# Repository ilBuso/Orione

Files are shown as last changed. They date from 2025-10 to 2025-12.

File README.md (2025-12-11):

# Orione

Orione is a custom 60% mechanical keyboard powered by Raspberry Pi Pico.

## Table of Contents

- [About the Project](#about-the-project)
- [Key Features](#key-features)
- [Making It Your Own](#making-it-your-own)
- [What You'll Need](#what-youll-need)
  - [Hardware Components](#hardware-components)
  - [Software Tools](#software-tools)
- [The PCB](#the-pcb)
- [The Chassis](#the-chassis)
- [Project layout](#project-layout)
- [Video and Presentation](#video-and-presentation)
- [The Team](#the-team)

## About the Project

The need for a keyboard with a rotary encoder that could be customized without compromising on functionality sparked the creation of this project. When existing options fell short of meeting these requirements, Orione was born: a custom 60% mechanical keyboard powered by the Raspberry Pi Pico, featuring fully customizable firmware and a dual-layer system that packs maximum functionality into a minimal footprint.

Orione is built around the compact 60% keyboard layout, which strips away the function row and number pad to create a more ergonomic typing experience. At its heart is the Raspberry Pi Pico microcontroller, an affordable and reliable brain that handles everything from key presses to USB communication.

What makes Orione special is its programmable dual-layer system. Through a dedicated function key, you can access an entirely separate layer of key functions, meaning you don't lose any functionality despite the smaller form factor. It's like having two keyboards in one compact package.

## Key Features

The design philosophy behind Orione was simple: create something that feels personal and works exactly the way I want it to. Here's what that translated into:

The **60% layout** keeps everything within easy reach, no more stretching for distant keys or function rows. A **dual-layer system** accessed through a dedicated function key means I haven't sacrificed any functionality for compactness.

The **rotary encoder** handles volume control beautifully, with raise, lower, and mute functionality at your fingertips. There's also a **Caps Lock LED indicator** for quick visual feedback.

For switches are for the most part **Gateron Yellow switches** that provide smooth linear action for most keys, while **Gateron Blue switches** offer tactile feedback on select keys where I wanted that extra confirmation.

Most importantly, the firmware is **fully customizable**. Every key can be remapped, every function can be changed. The Raspberry Pi Pico makes this possible, and the open-source nature of the project means you're never locked into my choices.

## Making It Your Own

One of Orione's defining features is how easily you can make it yours. The firmware is completely open and modifiable. Want to change what a key does? Remap the function layer? It's all possible:

Start by editing the keymap configuration files to match your preferences. Once you're happy with your changes, recompile the firmware and flash it to your Raspberry Pi Pico. That's it, you've got a personalized keyboard that works exactly the way you want it to.

## What You'll Need

### Hardware Components

Building Orione requires a carefully selected set of components. You'll need a **Raspberry Pi Pico** as the microcontroller, it's the brain of the operation. The **rotary encoder** provides that tactile volume control I was after, while a **LED** serves as the Caps Lock indicator.s

For the switches, you'll need **62 mechanical switches** total. You'll also need a matching set of **62 keycaps** and **62 diodes** for the key matrix.

Finally, there's the **custom PCB** that I designed specifically for this project, bringing all these components together in a compact and functional layout.

### Software Tools

The development environment revolves around **VS Code**, which I used for writing and debugging the firmware. For the PCB design, **KiCad** handled both the schematics and the layout. The chassis and 3D components were modeled in **Blender**.

On the firmware side, the project uses the **Raspberry Pi Pico C/C++ SDK**, following the official _Getting Started guide_ will get you set up properly. The **TinyUSB Library** is crucial here, as it enables USB HID communication between the Pico and your computer through the micro USB port, making the keyboard actually function as, well, a keyboard.

## The PCB

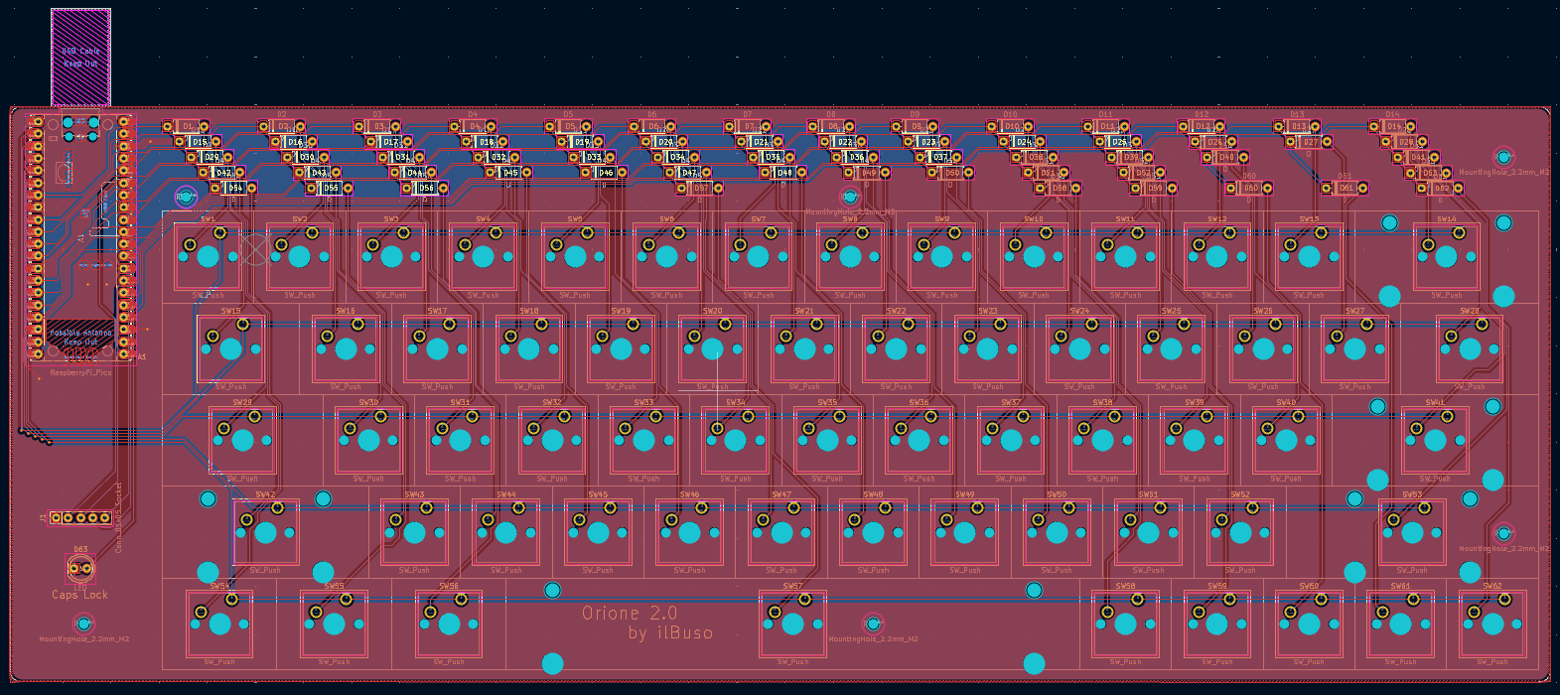
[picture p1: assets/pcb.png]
PCB


## The Chassis

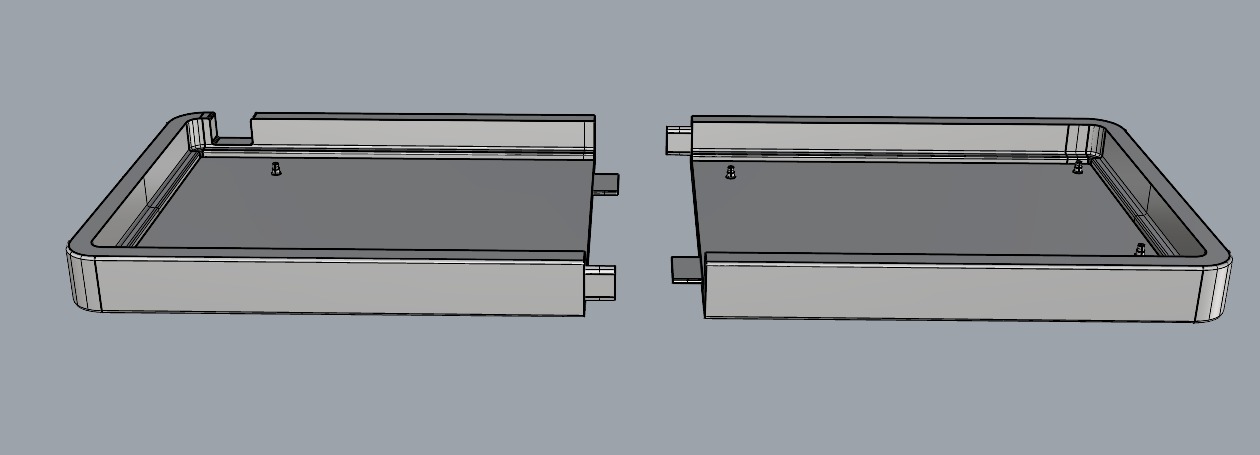
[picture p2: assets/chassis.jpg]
Chassis


## Project layout

```
/
├───datasheets
|   └───...
├───firmware
│   ├───config
│   └───src
│       ├───init
│       │   ├───init.h
│       │   └───init.c
│       ├───interrupts
│       │   ├───interrupts.h
│       │   └───interrupts.c
│       ├───matrix
│       │   ├───keymap
│       │   │   ├───keymap.h
│       │   │   └───keymap.c
│       │   └───scan_rows
│       │       ├───scan_rows.h
│       │       └───scan_rows.c
│       ├───rotary_encoder
│       │   ├───rotary_encoder.h
│       │   └───rotary_encoder.c
│       └───usb
│           ├───usb_callbacks
│           │  ├───usb_callbacks.h
│           │  └───usb_callbacks.c
│           └───usb_descriptors
│              ├───usb_descriptors.h
│              └───usb_descriptors.c
├───pcb
│   └───...
└───chassis
    └───...
```

## Video and Presentation

[Video](https://youtu.be/jeuJEti2THU)

[Presentation](assets/Orione.pdf)

## The Team

In the team we collaborated closely with eachother, both in presence and through Github.

|Name|Github handle|
|---|---|
|Alessandro Busola| [@ilBuso](https://github.com/ilBuso)|
|Giulio Pimenoff Verdolin|[@Giuliopime](https://github.com/Giuliopime)|
|Michele Pezzo|[@MichelePZZ](https://github.com/MichelePZZ)|
|Daniel Biz|[@BizDaniel](https://github.com/BizDaniel)|

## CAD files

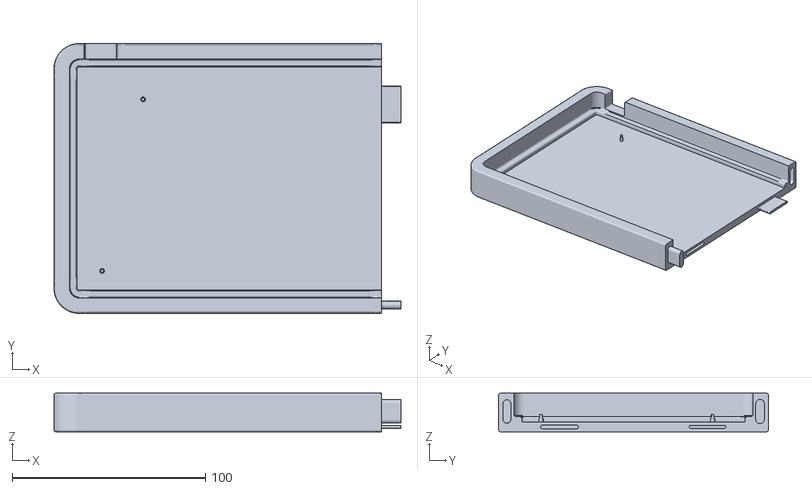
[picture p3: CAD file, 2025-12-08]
chassis/Chasis_Hor_1.stl
179.4 x 139.5 x 20.0

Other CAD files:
chassis/Chasis_Hor_2.stl

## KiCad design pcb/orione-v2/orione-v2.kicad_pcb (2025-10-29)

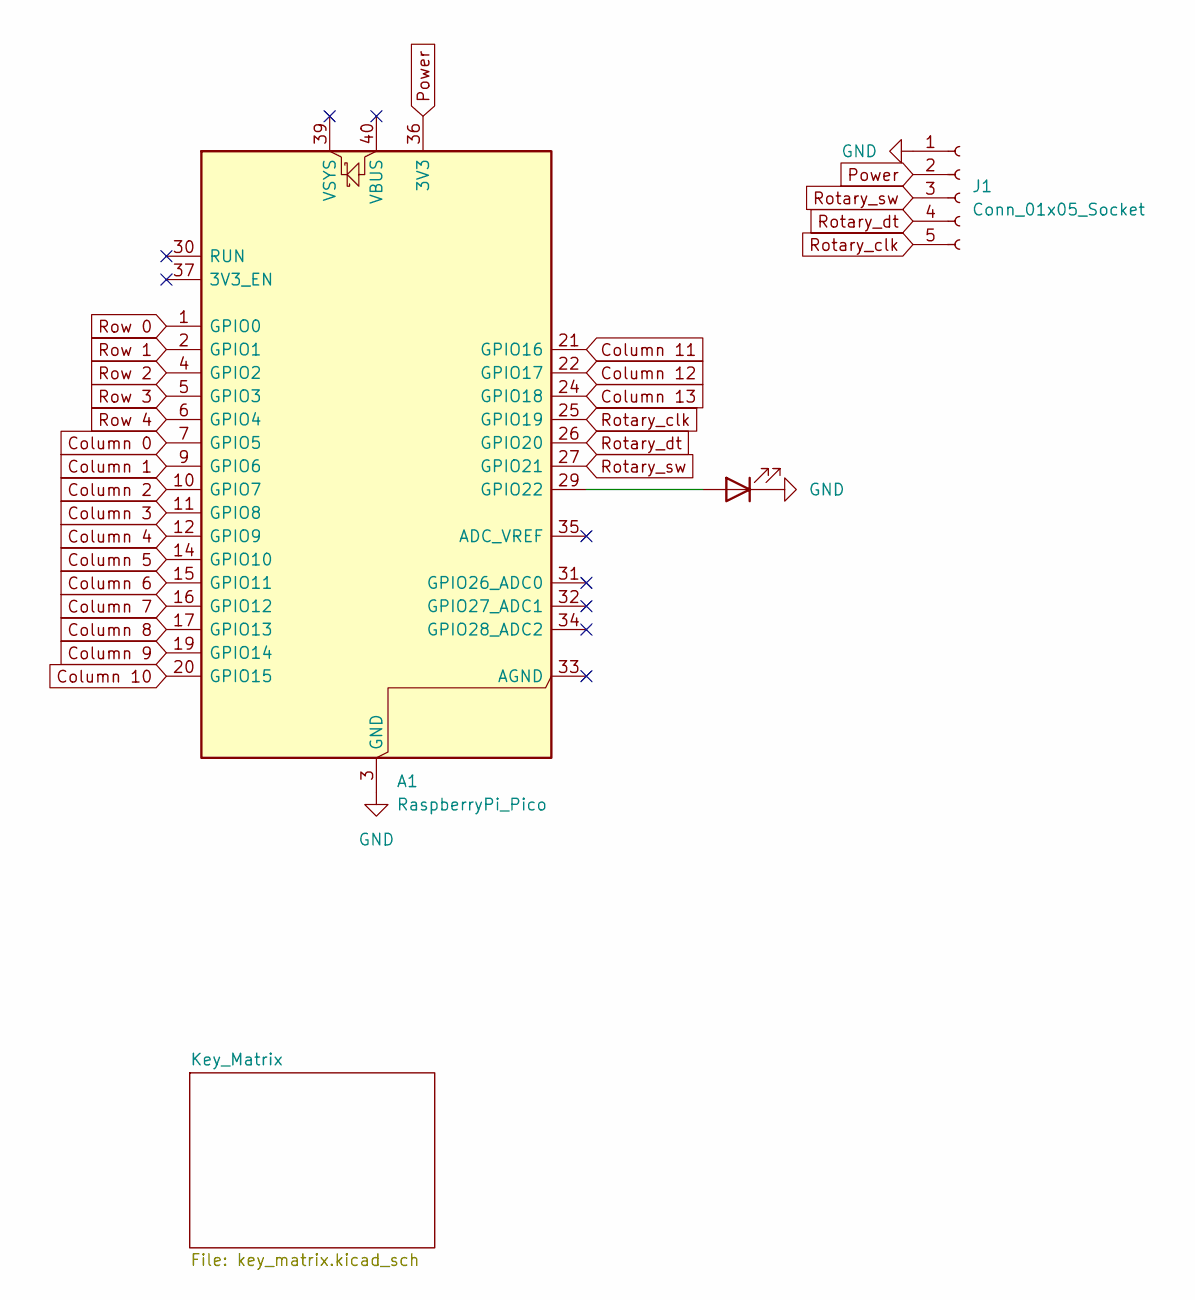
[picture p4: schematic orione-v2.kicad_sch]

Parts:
A1: RaspberryPi_Pico; RaspberryPi_Pico_Common_Unspecified
D63: LED; LED_D5.0mm
J1: Conn_01x05_Socket; PinSocket_1x05_P2.54mm_Vertical

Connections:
Column 0: A1.7 (GPIO5); also elsewhere on the board
Column 1: A1.9 (GPIO6); also elsewhere on the board
Column 2: A1.10 (GPIO7); also elsewhere on the board
Column 3: A1.11 (GPIO8); also elsewhere on the board
Column 4: A1.12 (GPIO9); also elsewhere on the board
Column 5: A1.14 (GPIO10); also elsewhere on the board
Column 6: A1.15 (GPIO11); also elsewhere on the board
Column 7: A1.16 (GPIO12); also elsewhere on the board
Column 8: A1.17 (GPIO13); also elsewhere on the board
Column 9: A1.19 (GPIO14); also elsewhere on the board
Column 10: A1.20 (GPIO15); also elsewhere on the board
Column 11: A1.21 (GPIO16); also elsewhere on the board
Column 12: A1.22 (GPIO17); also elsewhere on the board
Column 13: A1.24 (GPIO18); also elsewhere on the board
GND: A1.3 (GND), A1.8 (GND), A1.13 (GND), A1.18 (GND), A1.23 (GND), A1.28 (GND), A1.38 (GND), D63.1 (K), J1.1
unnamed: A1.29 (GPIO22), D63.2 (A)
Power: A1.36 (3V3), J1.2
Rotary_clk: A1.25 (GPIO19), J1.5
Rotary_dt: A1.26 (GPIO20), J1.4
Rotary_sw: A1.27 (GPIO21), J1.3
Row 0: A1.1 (GPIO0); also elsewhere on the board
Row 1: A1.2 (GPIO1); also elsewhere on the board
Row 2: A1.4 (GPIO2); also elsewhere on the board
Row 3: A1.5 (GPIO3); also elsewhere on the board
Row 4: A1.6 (GPIO4); also elsewhere on the board

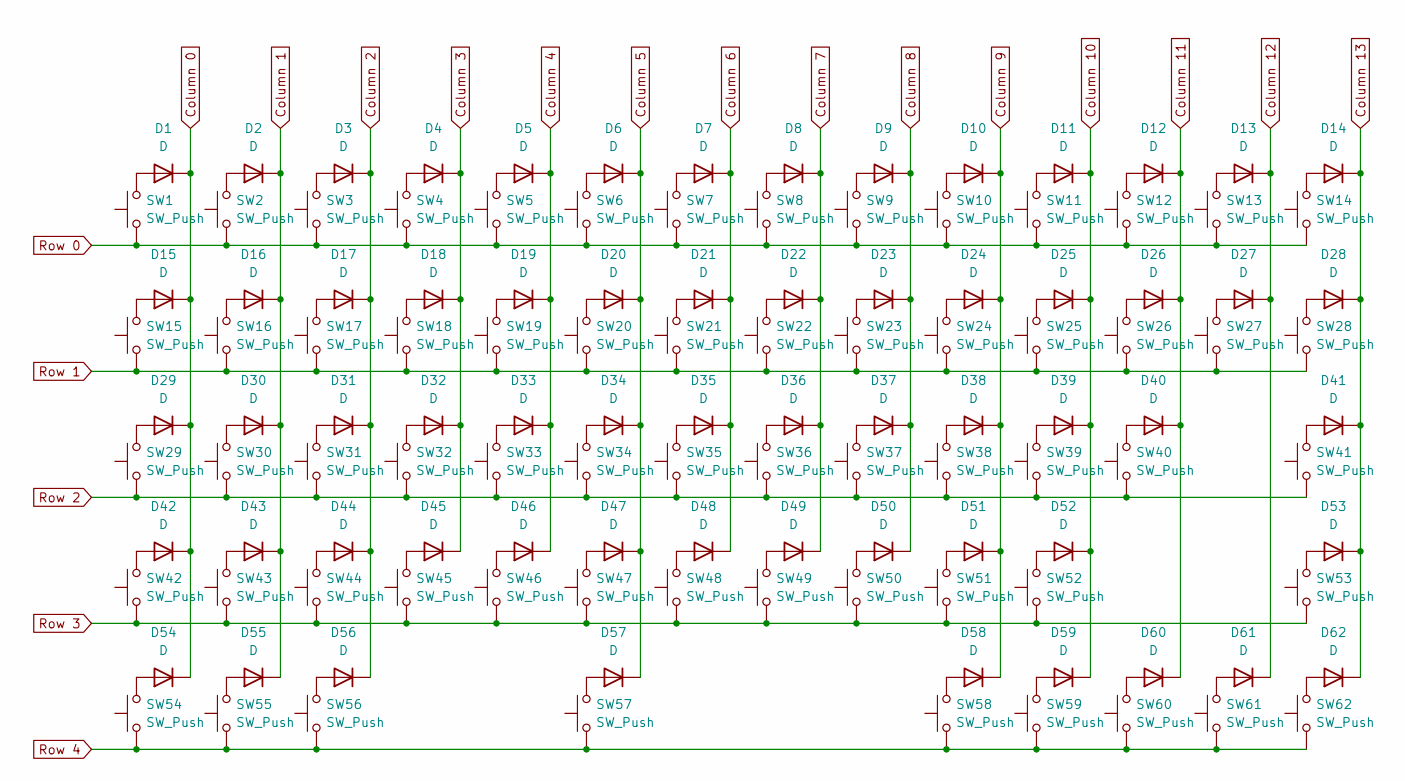
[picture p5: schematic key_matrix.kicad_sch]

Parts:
D1, D2, D3, D4, D5, D6, D7, D8, D9, D10, D11, D12, D13, D14, D15, D16, D17, D18, D19, D20, D21, D22, D23, D24, D25, D26, D27, D28, D29, D30, D31, D32, D33, D34, D35, D36, D37, D38, D39, D40, D41, D42, D43, D44, D45, D46, D47, D48, D49, D50, D51, D52, D53, D54, D55, D56, D57, D58, D59, D60, D61, D62: D; D_A-405_P7.62mm_Horizontal
SW1, SW2, SW3, SW4, SW5, SW6, SW7, SW8, SW9, SW10, SW11, SW12, SW13, SW16, SW17, SW18, SW19, SW20, SW21, SW22, SW23, SW24, SW25, SW26, SW27, SW30, SW31, SW32, SW33, SW34, SW35, SW36, SW37, SW38, SW39, SW40, SW43, SW44, SW45, SW46, SW47, SW48, SW49, SW50, SW51, SW52, SW58, SW59, SW60, SW61, SW62: SW_Push; SW_Cherry_MX_1.00u_PCB
SW14: SW_Push; SW_Cherry_MX_2.00u_PCB
SW15, SW28: SW_Push; SW_Cherry_MX_1.50u_PCB
SW29: SW_Push; SW_Cherry_MX_1.75u_PCB
SW41, SW42: SW_Push; SW_Cherry_MX_2.25u_PCB
SW53: SW_Push; SW_Cherry_MX_2.75u_PCB
SW54, SW55, SW56: SW_Push; SW_Cherry_MX_1.25u_PCB
SW57: SW_Push; SW_Cherry_MX_6.25u_PCB

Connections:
Column 0: D1.1 (K), D15.1 (K), D29.1 (K), D42.1 (K), D54.1 (K); also elsewhere on the board
Column 1: D2.1 (K), D16.1 (K), D30.1 (K), D43.1 (K), D55.1 (K); also elsewhere on the board
Column 2: D3.1 (K), D17.1 (K), D31.1 (K), D44.1 (K), D56.1 (K); also elsewhere on the board
Column 3: D4.1 (K), D18.1 (K), D32.1 (K), D45.1 (K); also elsewhere on the board
Column 4: D5.1 (K), D19.1 (K), D33.1 (K), D46.1 (K); also elsewhere on the board
Column 5: D6.1 (K), D20.1 (K), D34.1 (K), D47.1 (K), D57.1 (K); also elsewhere on the board
Column 6: D7.1 (K), D21.1 (K), D35.1 (K), D48.1 (K); also elsewhere on the board
Column 7: D8.1 (K), D22.1 (K), D36.1 (K), D49.1 (K); also elsewhere on the board
Column 8: D9.1 (K), D23.1 (K), D37.1 (K), D50.1 (K); also elsewhere on the board
Column 9: D10.1 (K), D24.1 (K), D38.1 (K), D51.1 (K), D58.1 (K); also elsewhere on the board
Column 10: D11.1 (K), D25.1 (K), D39.1 (K), D52.1 (K), D59.1 (K); also elsewhere on the board
Column 11: D12.1 (K), D26.1 (K), D40.1 (K), D60.1 (K); also elsewhere on the board
Column 12: D13.1 (K), D27.1 (K), D61.1 (K); also elsewhere on the board
Column 13: D14.1 (K), D28.1 (K), D41.1 (K), D53.1 (K), D62.1 (K); also elsewhere on the board
unnamed: D1.2 (A), SW1.2
unnamed: D2.2 (A), SW2.2
unnamed: D3.2 (A), SW3.2
unnamed: D4.2 (A), SW4.2
unnamed: D5.2 (A), SW5.2
unnamed: D6.2 (A), SW6.2
unnamed: D7.2 (A), SW7.2
unnamed: D8.2 (A), SW8.2
unnamed: D9.2 (A), SW9.2
unnamed: D10.2 (A), SW10.2
unnamed: D11.2 (A), SW11.2
unnamed: D12.2 (A), SW12.2
unnamed: D13.2 (A), SW13.2
unnamed: D14.2 (A), SW14.2
unnamed: D15.2 (A), SW15.2
unnamed: D16.2 (A), SW16.2
unnamed: D17.2 (A), SW17.2
unnamed: D18.2 (A), SW18.2
unnamed: D19.2 (A), SW19.2
unnamed: D20.2 (A), SW20.2
unnamed: D21.2 (A), SW21.2
unnamed: D22.2 (A), SW22.2
unnamed: D23.2 (A), SW23.2
unnamed: D24.2 (A), SW24.2
unnamed: D25.2 (A), SW25.2
unnamed: D26.2 (A), SW26.2
unnamed: D27.2 (A), SW27.2
unnamed: D28.2 (A), SW28.2
unnamed: D29.2 (A), SW29.2
unnamed: D30.2 (A), SW30.2
unnamed: D31.2 (A), SW31.2
unnamed: D32.2 (A), SW32.2
unnamed: D33.2 (A), SW33.2
unnamed: D34.2 (A), SW34.2
unnamed: D35.2 (A), SW35.2
unnamed: D36.2 (A), SW36.2
unnamed: D37.2 (A), SW37.2
unnamed: D38.2 (A), SW38.2
unnamed: D39.2 (A), SW39.2
unnamed: D40.2 (A), SW40.2
unnamed: D41.2 (A), SW41.2
unnamed: D42.2 (A), SW42.2
unnamed: D43.2 (A), SW43.2
unnamed: D44.2 (A), SW44.2
unnamed: D45.2 (A), SW45.2
unnamed: D46.2 (A), SW46.2
unnamed: D47.2 (A), SW47.2
unnamed: D48.2 (A), SW48.2
unnamed: D49.2 (A), SW49.2
unnamed: D50.2 (A), SW50.2
unnamed: D51.2 (A), SW51.2
unnamed: D52.2 (A), SW52.2
unnamed: D53.2 (A), SW53.2
unnamed: D54.2 (A), SW54.2
unnamed: D55.2 (A), SW55.2
unnamed: D56.2 (A), SW56.2
unnamed: D57.2 (A), SW57.2
unnamed: D58.2 (A), SW58.2
unnamed: D59.2 (A), SW59.2
unnamed: D60.2 (A), SW60.2
unnamed: D61.2 (A), SW61.2
unnamed: D62.2 (A), SW62.2
Row 0: SW1.1, SW2.1, SW3.1, SW4.1, SW5.1, SW6.1, SW7.1, SW8.1, SW9.1, SW10.1, SW11.1, SW12.1, SW13.1, SW14.1; also elsewhere on the board
Row 1: SW15.1, SW16.1, SW17.1, SW18.1, SW19.1, SW20.1, SW21.1, SW22.1, SW23.1, SW24.1, SW25.1, SW26.1, SW27.1, SW28.1; also elsewhere on the board
Row 2: SW29.1, SW30.1, SW31.1, SW32.1, SW33.1, SW34.1, SW35.1, SW36.1, SW37.1, SW38.1, SW39.1, SW40.1, SW41.1; also elsewhere on the board
Row 3: SW42.1, SW43.1, SW44.1, SW45.1, SW46.1, SW47.1, SW48.1, SW49.1, SW50.1, SW51.1, SW52.1, SW53.1; also elsewhere on the board
Row 4: SW54.1, SW55.1, SW56.1, SW57.1, SW58.1, SW59.1, SW60.1, SW61.1, SW62.1; also elsewhere on the board

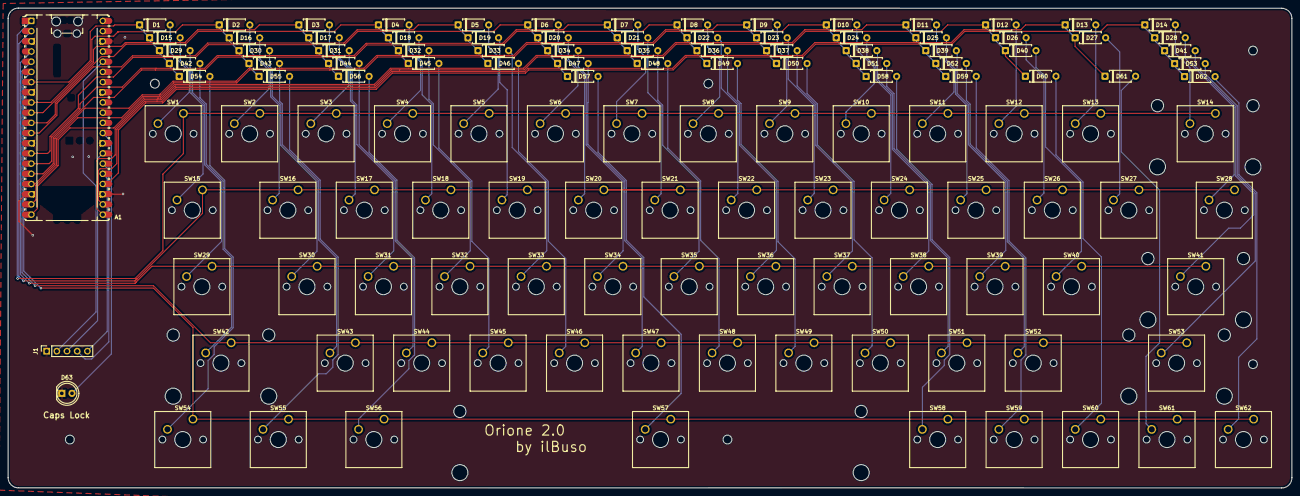
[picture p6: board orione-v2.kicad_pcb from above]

Board: 2 copper layers, 319.9 x 119.6 mm, 127 parts (0 on the bottom side), 87 nets.

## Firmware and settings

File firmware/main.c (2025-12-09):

/**
 * @file main.c
 * @brief Main entry point for Orione keyboard firmware
 * 
 * Handles USB device initialization, main loop execution, LED status blinking,
 * and HID report generation for both keyboard matrix and rotary encoder inputs.
 */

#include <stdlib.h>
#include <stdio.h>
#include <string.h>

#include "pico/stdlib.h"
#include "bsp/board_api.h"
#include "tusb.h"

#include "src/usb/usb_descriptors/usb_descriptors.h"
#include "src/usb/usb_callbacks/usb_callbacks.h"
#include "src/global.h"
#include "src/init/init.h"
#include "src/matrix/scan_rows/scan_rows.h"

//--------------------------------------------------------------------+

uint32_t blink_interval_ms = BLINK_NOT_MOUNTED;

keyboard_state_t kbd_state = {
    .has_new_key = false,
    .pressed_keys_count = 0,
    .current_layer = 0
};

//--------------------------------------------------------------------+

/**
 * @brief Blink onboard LED based on USB connection status
 * 
 * Provides visual feedback of the device state:
 * - Fast blink (250ms): Not mounted/connected
 * - Slow blink (1000ms): Mounted and ready
 * - Very slow blink (2500ms): Suspended
 * - Solid on: Caps Lock active
 * - Off: Blink disabled
 */
void led_blinking_task(void) {
    static uint32_t start_ms = 0;
    static bool led_state = false;

    // blink is disabled
    if (!blink_interval_ms) return;

    // Blink every interval ms
    if (board_millis() - start_ms < blink_interval_ms) return;
    start_ms += blink_interval_ms;

    board_led_write(led_state);
    led_state = 1 - led_state;
}

/**
 * @brief Process and send HID reports for keyboard and rotary encoder
 * 
 * Polls keyboard state and rotary encoder at 10ms intervals (required by TinyUSB).
 * Handles:
 * - Remote wakeup when suspended
 * - Keyboard key press/release reports
 * - Rotary encoder volume control (rotation) and mute (button press)
 */
void hid_task(void) {
    // Poll every 10ms -> required by TinyUSB
    const uint32_t interval_ms = 10;
    static uint32_t start_ms = 0;

    // check interval
    if (board_millis() - start_ms < interval_ms) return;
    start_ms += interval_ms;

    // Remote wakeup if suspended
    if (tud_suspended()) {
        if (kbd_state.has_new_key) {
            tud_remote_wakeup();
            kbd_state.has_new_key = false;
        }
        return;
    } else {
        if (tud_hid_ready()) {
            // Handle keyboard input
            if (kbd_state.has_new_key) {
                // Clear flag
                kbd_state.has_new_key = false;
                // send report
                send_hid_report(REPORT_ID_KEYBOARD, 0);
            }

            // Handle rotary encoder input
            int8_t direction;
            bool button_pressed;
            
            rotary_encoder_get_state(&direction, &button_pressed);
            
            if (button_pressed) {
                // mute/unmute
                send_hid_report(REPORT_ID_CONSUMER_CONTROL, HID_USAGE_CONSUMER_MUTE);
                sleep_ms(10);
                send_hid_report(REPORT_ID_CONSUMER_CONTROL, 0);
            } else if (direction > 0) {
                // volume up
                send_hid_report(REPORT_ID_CONSUMER_CONTROL, HID_USAGE_CONSUMER_VOLUME_INCREMENT);
                sleep_ms(10);
                send_hid_report(REPORT_ID_CONSUMER_CONTROL, 0);
            } else if (direction < 0) {
                // volume down
                send_hid_report(REPORT_ID_CONSUMER_CONTROL, HID_USAGE_CONSUMER_VOLUME_DECREMENT);
                sleep_ms(10);
                send_hid_report(REPORT_ID_CONSUMER_CONTROL, 0);
            }

        }
    }
}

/**
 * @brief Initialize all hardware peripherals
 * 
 * Configures GPIO pins and interrupts for:
 * - Keyboard matrix (rows, columns, interrupts)
 * - Rotary encoder (CLK, DT, SW pins and interrupts)
 * - Status LEDs (Caps Lock indicator)
 */
void init(void) {
    // keyboard
    init_keyboard_gpio();
    init_keyboard_interrupts();
    
    // rotary encoder
    init_rotary_encoder_gpio();
    init_rotary_encoder_interrupts();

    // Caps-Lock led
    init_led();
}

//--------------------------------------------------------------------+

/**
 * @brief Main program entry point
 * 
 * Initializes the USB device stack and hardware peripherals, then enters
 * the main loop to continuously process USB tasks, update LED status,
 * and handle HID input/output.
 * 
 * @return Never returns (infinite loop)
 */
int main(void) {
    // init TinyUSB
    board_init();
    tud_init(BOARD_TUD_RHPORT);
    if (board_init_after_tusb) {
        board_init_after_tusb();
    }

    // init sys
    init();

    // loop
    while (1) {
        tud_task();
        led_blinking_task();
        hid_task();
    }
}

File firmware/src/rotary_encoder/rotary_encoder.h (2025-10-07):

/**
 * @file rotary_encoder.h
 * @brief Rotary encoder definitions and state structure
 * 
 * Pin definitions, debounce timing constants, and state structure for
 * KY-040 rotary encoder module with integrated push button.
 */

#ifndef ROTARY_ENCODER_H
#define ROTARY_ENCODER_H

    #include <stdint.h>
    #include <stdbool.h>
    
    #include "pico/stdlib.h"
    #include "hardware/sync.h"
    
    #define ROTARY_CLK 19    // CLK pin (A)
    #define ROTARY_DT 20     // DT pin (B)
    #define ROTARY_SW 21     // Switch pin (button)

    // Rotary encoder state
    typedef struct {
        volatile int8_t direction;     // -1 for CCW, 1 for CW, 0 for no change
        volatile bool button_pressed;   // true when button is pressed
        volatile bool has_event;        // true when there's a new event to process
    } rotary_encoder_state_t;

    extern uint32_t last_encoder_time;
    extern uint32_t last_button_time;
    extern uint8_t last_clk_state;
    extern rotary_encoder_state_t rotary_state;

    // Get current state (call from main loop)
    void rotary_encoder_get_state(int8_t* direction, bool* button_pressed);

#endif /* ROTARY_ENCODER_H */

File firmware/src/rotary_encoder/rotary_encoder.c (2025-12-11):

/**
 * @file rotary_encoder.c
 * @brief Rotary encoder state management
 * 
 * Manages rotary encoder state including rotation direction and button
 * press status. Provides interrupt-safe atomic access for reading and
 * clearing encoder events from the main loop.
 */

#include "rotary_encoder.h"

//--------------------------------------------------------------------+

uint32_t last_encoder_time = 0;             // Timestamp of last encoder rotation event
uint32_t last_button_time = 0;              // Timestamp of last button press event
uint8_t last_clk_state = 1;                 // Previous state of CLK pin for edge detection
rotary_encoder_state_t rotary_state = {0};  // Current encoder state


//--------------------------------------------------------------------+

/**
 * @brief Get and clear current rotary encoder state
 * 
 * Atomically reads the current encoder state (rotation direction and button
 * press) and clears the rotation direction and event flag for the next event.
 * The button_pressed state is preserved to allow distinguishing between
 * press and release events in the main loop. Uses interrupt disabling to
 * ensure thread-safe access between main loop and interrupt handlers.
 * 
 * @param direction Pointer to store rotation direction (-1=CCW, 0=none, 1=CW)
 * @param button_pressed Pointer to store button state (true if pressed, false if released)
 */
void rotary_encoder_get_state(int8_t* direction, bool* button_pressed) {
    if (!rotary_state.has_event) {
        *direction = 0;
        *button_pressed = false;
        return;
    }
    
    uint32_t status = save_and_disable_interrupts();
    
    *direction = rotary_state.direction;
    *button_pressed = rotary_state.button_pressed;
    
    // Clear solo direction, button_pressed rimane per indicare press vs release
    rotary_state.direction = 0;
    rotary_state.has_event = false;
    
    restore_interrupts(status);
}

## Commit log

2024-12-30 Added version 1.0 of the pcb
    [orione.kicad_pcb, orione.kicad_sch]
2024-12-31 minor updtaes to pcb
    [orione.kicad_pcb, orione.kicad_sch]
2024-12-31 Updated MATERIALS.md
2025-01-02 pcv v1
    [orione-v1.kicad_pcb, orione-v1.kicad_sch, orione.kicad_pcb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]
2025-01-02 pcv v1.1
    [orione-v1.kicad_pcb, orione-v1.kicad_sch]
2025-01-03 fixed GND
    [orione-v1.kicad_pcb, orione-v1.kicad_sch]
2025-01-03 fixed power trace
    [orione-v1.kicad_pcb]
2025-01-08 added hw for voltage divider
2025-01-08 added voltage divider
    [orione-v1.kicad_pcb, orione-v1.kicad_sch]
2025-01-08 added some uart sw steps
2025-01-08 added pin assignment sheet
2025-01-08 changed pin layout of uart
    [orione-v1.kicad_pcb, orione-v1.kicad_sch]
2025-01-14 added links to material and uploaded the datasheets
2025-01-15 modified pcb based on new parts
    [orione-v1.kicad_pcb, orione-v1.kicad_sch]
2025-01-20 implemented UART comunication
2025-02-25 updated material
2025-03-03 added Rotary Encoder and OLED Display
2025-03-03 added to pcb rotary encoder and oled dysplay
    [orione-v1.kicad_pcb, orione-v1.kicad_sch]
2025-03-10 interrupt-based implementation
2025-03-10 removed interrupt note
2025-03-10 un-commented power-saving mode
2025-03-18 possible fix interrupt cicle
    [global.c, init.c]
2025-03-18 fix: enable interrupt on scan_row
    [global.c]
2025-03-19 driver basics
2025-03-21 added draft for all driver scripts
2025-03-28 updated linux driver
2025-04-16 feat: basic profile switch detection
2025-10-05 added RPi pico datashett + updated README.md
2025-11-18 bug fix chaged debounce
    [interrupts.c]
2025-12-05 updated chassis image
2025-12-08 chassis 3D files
    [Chasis_Hor_1.stl, Chasis_Hor_2.stl]
2025-12-09 fixed gosting rotary encoder
    [interrupts.c, main.c]
2025-12-09 fixed consume buttons
2025-12-09 fixed quick pres on same column
    [interrupts.c]
2025-12-09 fixed rotary encoder button
    [init.c, interrupts.c, main.c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]
